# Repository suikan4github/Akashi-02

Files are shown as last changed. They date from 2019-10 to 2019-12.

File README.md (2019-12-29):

# Akashi-02
A test Jig for Murasaki-Library. Tested with audio codec board UMB-AD1361A.

## Functionality
This board is designed to test the audio interface functionality of the STM32 series MCU. The connectors can be directly mounted on the Nucleo 144 series board. With this board, the following audio interface can be tested :
- SAI peripheral (STM32F722, F746, H743)
- Simplex I2S peripheral (STM32F722, F746)
- Duplex I2S peripheral (STM32H743)

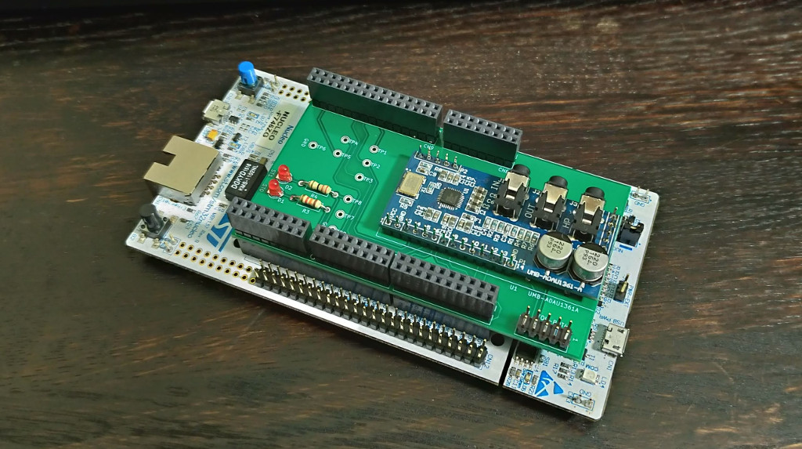
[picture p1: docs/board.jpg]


These functionalities are tested with following codec board as with I2C control line. 
- [UMB-ADAU1361A](http://dsps.shop-pro.jp/?pid=82798273)

## Development
- [KiCad 5.1](http://kicad-pcb.org/blog/2019/03/KiCad-5.1.0-Release/)
- [Nucleo F722ZE](https://www.st.com/en/evaluation-tools/nucleo-f722ze.html)
- [Nucleo F746ZG](https://www.st.com/ja/evaluation-tools/nucleo-f746zg.html)
- [Nucleo H743ZI](https://www.st.com/ja/evaluation-tools/nucleo-h743zi.html)

The schematics [can be donwloaded](docs/Akashi-02.pdf) as PDF format. 

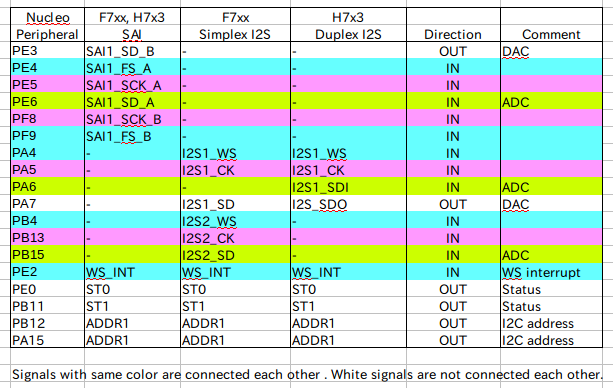
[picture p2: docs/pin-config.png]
Pin Configurations


## I2C address
By default, the I2C device address are fixed as ***0x38*** ( 7bit address ). If you want to change, you should modify the short bridge J2-J5 as following :
- J2 : Open by cutting the pattern.
- J3 : Close by soldering.
- J4 : Open by cutting the pattern.
- J5 : Close by soldering.

By above modification , the address can be controlled by GPIO PB12 and PA15. The address can be determined as following :

| b6 | b5 | b4 | b3 | b2 | b1    | b0   |
-----|----|----|----|----|-------|---- 
| 0  | 1  | 1  | 1  | 0  | PB12  | PA15 |

## Audio Port selection
This board allow to use SAI or I2S ( Both simplex and duplex). By default, ***Only SAI connection*** is allowed. The configuration of the board is as following : 

| Port | JP1     | JP6     | R5        |
-------|---------|---------|-----------
| SAI  | Opened  | Closed  | Removed   |
| I2S  | Closed  | Opened  | Removed   |
| Both | Opened  | Closed  | Installed |

"Both" is not recommended.

## Usage
To clone this project, follow :
```
git clone repository-of-this-project
git submodule update
```

The sample programs are published as [murasaki_samples_audio](https://github.com/suikan4github/murasaki_samples_audio) repositories. 

 To use these repository, follow the sequence :
 1. Clone the murasaki_samples_audio repository
 1. Import to CubeIDE

## License
This PCB design is released under the [Creative Commons Attribution 4.0 International license](https://creativecommons.org/licenses/by/4.0/). You are welcome to use this design for commercial purposes.

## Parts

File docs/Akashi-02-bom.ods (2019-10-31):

Reference | Value | Footprint | URL
U1 | UMB-ADAU1361A | Codec_Modules:UMB-ADAU1361A | 金子システム (http://dsps.shop-pro.jp/?pid=82798273)
TP9 | GND | TestPoint:TestPoint_THTPad_D2.0mm_Drill1.0mm | ~
TP6 | GND | TestPoint:TestPoint_THTPad_D2.0mm_Drill1.0mm | ~
TP5 | FS_B | TestPoint:TestPoint_THTPad_D2.0mm_Drill1.0mm | ~
TP4 | DAC | TestPoint:TestPoint_THTPad_D2.0mm_Drill1.0mm | ~
TP3 | ADC | TestPoint:TestPoint_THTPad_D2.0mm_Drill1.0mm | ~
TP2 | SCK_A | TestPoint:TestPoint_THTPad_D2.0mm_Drill1.0mm | ~
TP1 | FS_A | TestPoint:TestPoint_THTPad_D2.0mm_Drill1.0mm | ~
R5 | 33 | Resistor_THT:R_Axial_DIN0207_L6.3mm_D2.5mm_P10.16mm_Horizontal | ~
D2 | LED | LED_THT:LED_D3.0mm_Clear | ~
D1 | LED | LED_THT:LED_D3.0mm_Clear | ~
R4 | 1k | Resistor_THT:R_Axial_DIN0207_L6.3mm_D2.5mm_P10.16mm_Horizontal | ~
R3 | 1k | Resistor_THT:R_Axial_DIN0207_L6.3mm_D2.5mm_P10.16mm_Horizontal | ~
TP7 | ST0 | TestPoint:TestPoint_THTPad_D2.0mm_Drill1.0mm | ~
TP8 | ST1 | TestPoint:TestPoint_THTPad_D2.0mm_Drill1.0mm | ~
R2 | 2.2k | Resistor_THT:R_Axial_DIN0207_L6.3mm_D2.5mm_P10.16mm_Horizontal | ~
R1 | 2.2k | Resistor_THT:R_Axial_DIN0207_L6.3mm_D2.5mm_P10.16mm_Horizontal | ~
CN10 | Conn_02x17_Odd_Even | Connector_PinHeader_2.54mm:PinHeader_2x17_P2.54mm_Vertical | ‎ESQ-117-13-G-D‎
CN7 | Conn_02x10_Odd_Even | Connector_PinHeader_2.54mm:PinHeader_2x10_P2.54mm_Vertical | ‎ESQ-110-13-G-D‎
CN8 | Conn_02x08_Odd_Even | Connector_PinHeader_2.54mm:PinHeader_2x08_P2.54mm_Vertical | ESQ-108-13-G-D‎
CN9 | Conn_02x15_Odd_Even | Connector_PinHeader_2.54mm:PinHeader_2x15_P2.54mm_Vertical | ‎ESQ-115-13-G-D‎
J1 | Conn_02x05_Odd_Even | Connector_PinHeader_2.54mm:PinHeader_2x05_P2.54mm_Vertical | ~ | Not needed unless connecting

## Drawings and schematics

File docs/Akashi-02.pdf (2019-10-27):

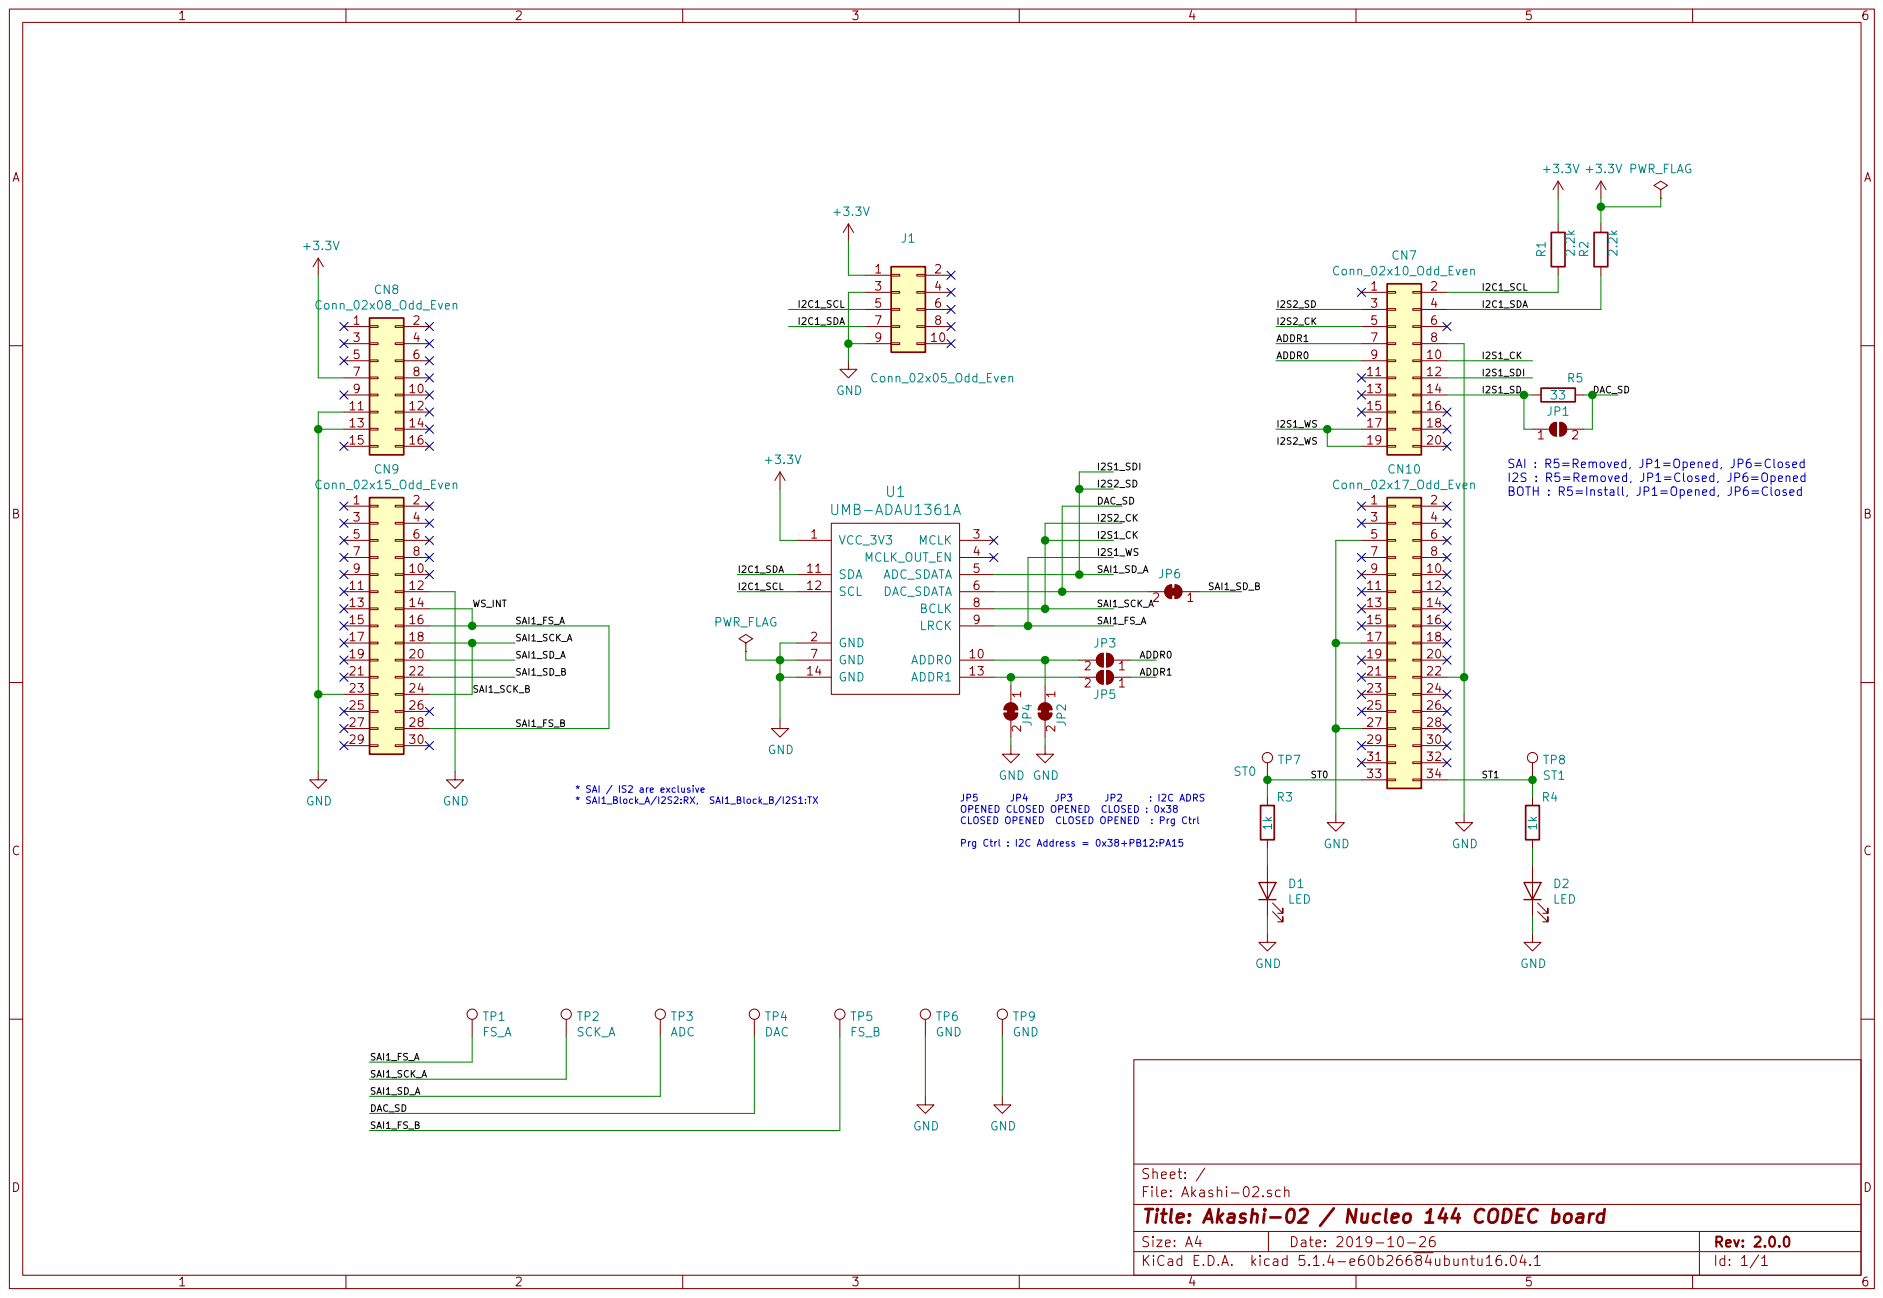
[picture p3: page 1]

I2S : R5=Removed, JP1=Closed, JP6=Opened
BOTH : R5=Install, JP1=Opened, JP6=Closed

Id: 1/1 Title: Akashi-02 / Nucleo 144 CODEC board

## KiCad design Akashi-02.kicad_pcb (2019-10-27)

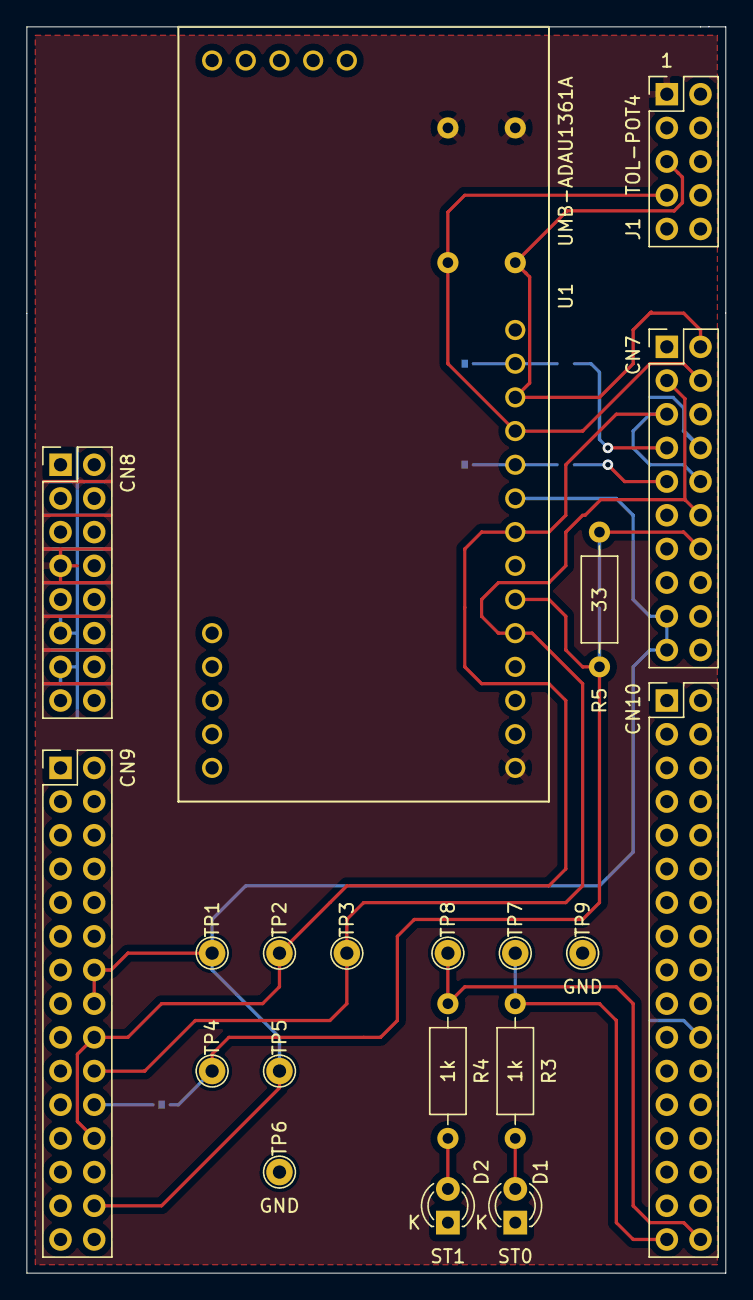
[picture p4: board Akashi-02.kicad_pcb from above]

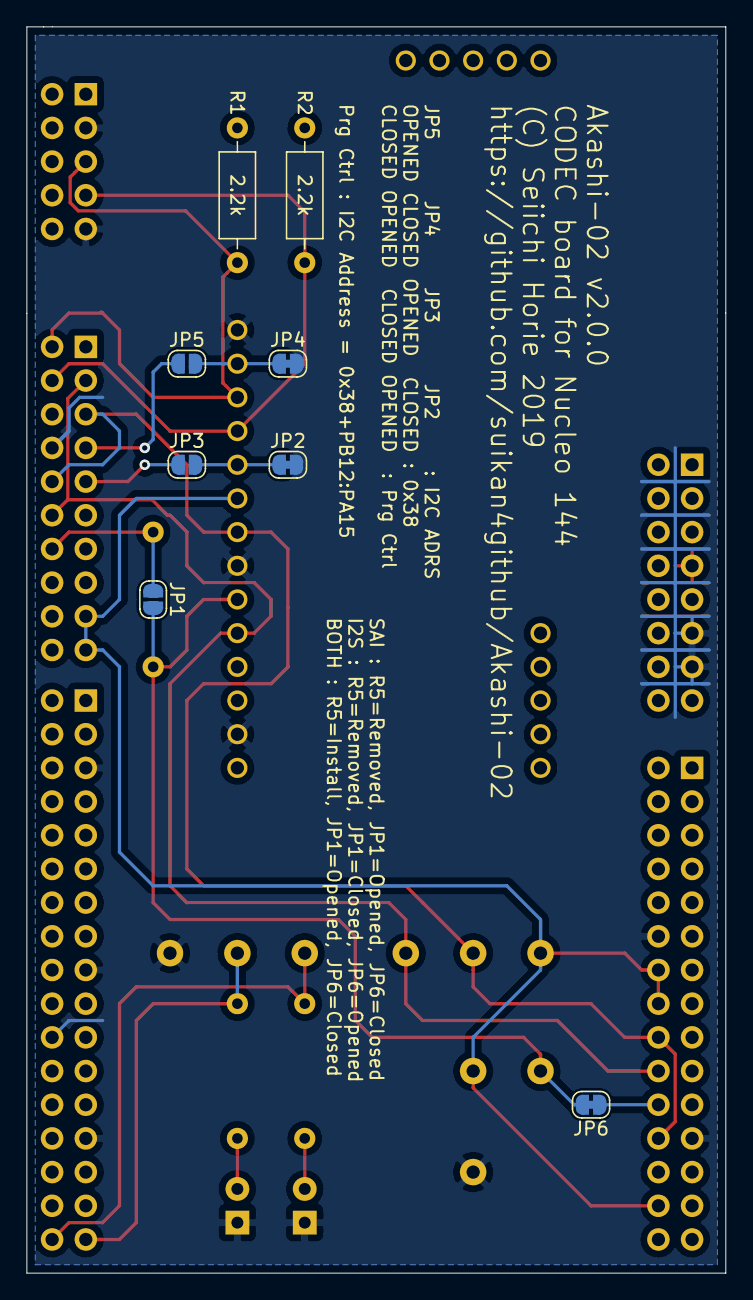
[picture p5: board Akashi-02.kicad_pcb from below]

Board: 2 copper layers, 52.7 x 94.0 mm, 28 parts (8 on the bottom side), 18 nets.

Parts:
CN7: Conn_02x10_Odd_Even; PinHeader_2x10_P2.54mm_Vertical
CN8: Conn_02x08_Odd_Even; PinHeader_2x08_P2.54mm_Vertical
CN9: Conn_02x15_Odd_Even; PinHeader_2x15_P2.54mm_Vertical
CN10: Conn_02x17_Odd_Even; PinHeader_2x17_P2.54mm_Vertical
D1, D2: LED; LED_D3.0mm_Clear
J1: Conn_02x05_Odd_Even; PinHeader_2x05_P2.54mm_Vertical
JP1, JP3, JP5: SolderJumper_2_Open; SolderJumper-2_P1.3mm_Open_RoundedPad1.0x1.5mm
JP2, JP4, JP6: SolderJumper_2_Bridged; SolderJumper-2_P1.3mm_Bridged_RoundedPad1.0x1.5mm
R1, R2: 2.2k; R_Axial_DIN0207_L6.3mm_D2.5mm_P10.16mm_Horizontal
R3, R4: 1k; R_Axial_DIN0207_L6.3mm_D2.5mm_P10.16mm_Horizontal
R5: 33; R_Axial_DIN0207_L6.3mm_D2.5mm_P10.16mm_Horizontal
TP1: FS_A; TestPoint_THTPad_D2.0mm_Drill1.0mm
TP2: SCK_A; TestPoint_THTPad_D2.0mm_Drill1.0mm
TP3: ADC; TestPoint_THTPad_D2.0mm_Drill1.0mm
TP4: DAC; TestPoint_THTPad_D2.0mm_Drill1.0mm
TP5: FS_B; TestPoint_THTPad_D2.0mm_Drill1.0mm
TP6, TP9: GND; TestPoint_THTPad_D2.0mm_Drill1.0mm
TP7: ST0; TestPoint_THTPad_D2.0mm_Drill1.0mm
TP8: ST1; TestPoint_THTPad_D2.0mm_Drill1.0mm
U1: UMB-ADAU1361A

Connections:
+3V3: CN8.7, J1.1, R1.1, R2.1, U1.1
/ADDR0: CN7.9, JP3.1
/ADDR1: CN7.7, JP5.1
/DAC_SD: JP1.2, JP6.2, R5.1, TP4.1, U1.6
/I2C1_SCL: CN7.2, J1.5, R1.2, U1.12
/I2C1_SDA: CN7.4, J1.7, R2.2, U1.11
/I2S1_CK: CN7.5, CN7.10, CN9.18, CN9.24, TP2.1, U1.8
/I2S1_SD: CN7.14, JP1.1, R5.2
/I2S1_SDI: CN7.3, CN7.12, CN9.20, TP3.1, U1.5
/I2S1_WS: CN7.17, CN7.19, CN9.14, CN9.16, CN9.28, TP1.1, TP5.1, U1.9
/SAI1_SD_B: CN9.22, JP6.1
/ST0: CN10.33, R3.1, TP7.1
/ST1: CN10.34, R4.1, TP8.1
GND: CN7.8, CN8.11, CN8.13, CN9.12, CN9.23, CN10.5, CN10.17, CN10.22, CN10.27, D1.1, D2.1, J1.3, J1.9, JP2.2, JP4.2, TP6.1, TP9.1, U1.2, U1.7, U1.14
unnamed: D1.2, R3.2
unnamed: D2.2, R4.2
unnamed: JP2.1, JP3.2, U1.10
unnamed: JP4.1, JP5.2, U1.13

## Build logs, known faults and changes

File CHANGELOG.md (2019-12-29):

# Change log
Record of the modification in project development.
## [Unreleased]

### Added
### Changed
### Deprecated
### Removed
### Fixed
### Security
### Known Issue

## [2.0.1] - 2019-12-29

### Added
### Changed
### Deprecated
### Removed
### Fixed
- [Issue 11 : Make external library access to local ](https://github.com/suikan4github/Akashi-02/issues/11)

### Security
### Known Issue

## [2.0.0] - 2019-12-12
SSM2603 support is dropped. 

### Added
### Changed
- [Issue 5 : U2 Pin4 is set ground by mistake](https://github.com/suikan4github/Akashi-02/issues/5)
- [Issue 6 : Remove SSM2603 support](https://github.com/suikan4github/Akashi-02/issues/6)
- [Issue 7 : Remove SPI support](https://github.com/suikan4github/Akashi-02/issues/7)
- [Issue 8 : Extend the board ](https://github.com/suikan4github/Akashi-02/issues/8)
- [Issue 9 : Modify readme ](https://github.com/suikan4github/Akashi-02/issues/9)

### Deprecated
### Removed
### Fixed
### Security
### Known Issue

## [1.0.2] - 2019-05-12

### Added
### Changed
### Deprecated
### Removed
### Fixed
- [Issue 4 : CODEC identification is wrong.](https://github.com/suikan4github/Akashi-02/issues/4)
The previous fix was not enough

### Security
### Known Issue

## [1.0.1] - 2019-04-14

### Added
### Changed
-[Issue 2 : Copy right is too small ](https://github.com/suikan4github/Akashi-02/issues/2)

### Deprecated
### Removed
### Fixed
- [Issue 1 : Test pin hole is too small ](https://github.com/suikan4github/Akashi-02/issues/1)
- [Issue 3 : Update footprint ](https://github.com/suikan4github/Akashi-02/issues/3)
- [Issue 4 : CODEC identification is wrong.](https://github.com/suikan4github/Akashi-02/issues/4)

### Security
### Known Issue

## [1.0.0] - 2019-03-01
Initial release. 

### Added
### Changed
### Deprecated
### Removed
### Fixed
### Security

[Unreleased]: https://github.com/suikan4github/Akashi-02/compare/v2.0.1...develop
[2.0.1]: https://github.com/suikan4github/Akashi-02/compare/v2.0.0...v2.0.1
[2.0.0]: https://github.com/suikan4github/Akashi-02/compare/v1.0.2...v2.0.0
[1.0.2]: https://github.com/suikan4github/Akashi-02/compare/v1.0.1...v1.0.2
[1.0.1]: https://github.com/suikan4github/Akashi-02/compare/v1.0.0...v1.0.1
[1.0.0]: https://github.com/suikan4github/Akashi-02/compare/v1.0.0...v0.0.0

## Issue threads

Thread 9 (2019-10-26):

Modify readme

suikan4github, 2019-10-26:
Many things have been changed. Need to update the readme.

- Supported Codec
- Supported Interface.
- Pin connection
- Configuration of CODEC address
- Configuration of I2C/SPI selection.

Closed 2019-12-29.

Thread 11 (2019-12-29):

Make external library access to local

suikan4github, 2019-12-29:
The KiCAD doesn't support external library access as a portable project.

TO make it local, we should change to local access.

suikan4github, 2019-12-29:
Merged to develop. Ready to release.

Closed 2019-12-29.

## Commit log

2019-03-28 Moved from old project
    [Akashi-02.kicad_pcb, Akashi-02.sch]
2019-03-31 Added README.md
    Prepare to be public, after the submittion of gerber to fab.
    [Akashi-02-bom.ods, Akashi-02-pin-config.ods, Akashi-02.kicad_pcb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]
2019-04-14 Change drill size of the test point
    Issue : Test pin hole is too small #1
    https://github.com/suikan4github/Akashi-02/issues/1
    [Akashi-02.kicad_pcb, Akashi-02.sch]
2019-04-14 Change size of the COPYRIGHT
    Issue : Copy right is too small #2
    https://github.com/suikan4github/Akashi-02/issues/2
    [Akashi-02.kicad_pcb]
2019-04-14 Change drill size of the modules
    Issue 3 : Update footprint
    https://github.com/suikan4github/Akashi-02/issues/3
    [Akashi-02.kicad_pcb]
2019-04-14 Generate gerber
    [pcb.drl, pcb.gbl, pcb.gbo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]
2019-04-14 Added Schematics
2019-04-17 Fixed codec identification
    Issue : CODEC identification is wrong. #4
    https://github.com/suikan4github/Akashi-02/issues/4
    [Akashi-02.kicad_pcb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]
2019-05-12 Fix the codec identification
    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
    [Akashi-02.kicad_pcb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]
2019-10-26 Change the board function and figure.
    Issue 5 : U2 Pin4 is set ground by mistake
    https://github.com/suikan4github/Akashi-02/issues/5
    Issue 6 : Remove SSM2603 support
    https://github.com/suikan4github/Akashi-02/issues/6
    Issue 7 : Remove SPI support
    https://github.com/suikan4github/Akashi-02/issues/7
    Issue 8 : Extend the board
    https://github.com/suikan4github/Akashi-02/issues/8
    [Akashi-02-pin-config.ods, Akashi-02.kicad_pcb, Akashi-02.sch]
2019-10-27 Added TOL-POT4 connector. Preparing to release.
    - Updated README.md
    - Updated pin-config.png
    - Updated gerber
    - Updated schematics in PDF
    [Akashi-02-bom.ods, Akashi-02-pin-config.ods, Akashi-02.kicad_pcb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]
2019-10-31 Ordered version 2.0.0
    [Akashi-02-bom.ods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]
2019-12-11 Added phot of the board.
